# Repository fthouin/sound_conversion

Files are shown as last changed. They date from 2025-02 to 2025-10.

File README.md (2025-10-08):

# Sub Sound-Conversion
Convertissons 4 boites de transport en merisier baltique de lasers femtoseconde Lituanniens (Light Conversion) en subwoofers!

**Avant**



**Après**



## Objectifs
- Obtenir des basses plus profondes pour bien rendre la diversité de styles musicaux du collectif Cocktail Sonore
- Avoir des enceintes efficaces pour permettre l'utilisation de batteries
- Permettre le transport à vélo
- Donner une nouvelle vie à des matériaux usagés

## Matériaux
Les dimensions des boites sont contenues dans le fichier `boite_lightcon_C231999.FCStd` (voir le tableur `dim` à l'intérieur). Ce fichier peut être ouvert avec [FreeCAD](https://www.freecad.org/). Une photo des boites se trouve dans le fichier `boite.jpg`

## Moteur

La conception s'articule autour du [Eminence 12LFA](https://eminence.com/products/delta_12lfa) dont la feuille de spécification se trouve dans `\Datasheets`.

## Concept original

Nous basons notre conception sur le [POC7 de Brian Steele](https://www.diysubwoofers.org/projects/other/POC7/) modifié pour faciliter la construction avec les matériaux disponibles

## Modèles

Les modèles de conception et de fabrication sont contenus dans le fichier FreeCAD V1 `./Simulations/gfold.FCStd`. Les paramètres ajustables du modèle se trouvent dans le chiffrier `dims` du fichier. Les dimensions internes, le rapport entre la hauteure des premières et deuxièmes segments du chemin acoustique pliés et la hauteure totale de la boite ainsi que le décalage du driver par rapport au premier plis du tube peuvent être ajustés pour optimiser les performances acoustiques.

### Simulations
 Dans ce fichier, le dossier Simulations contient un objet `soundpath`. Celui-ci contient un dessin de la cavité acoustique et des quatres segments (`sound_path_X`) qui la compose. Leur longueur est automatiquement calculée et transcrite dans le chiffrier `hornresp`. Ce classeur contient aussi l'aire des sections de ces segments, elles-aussi automatiquement calculées.

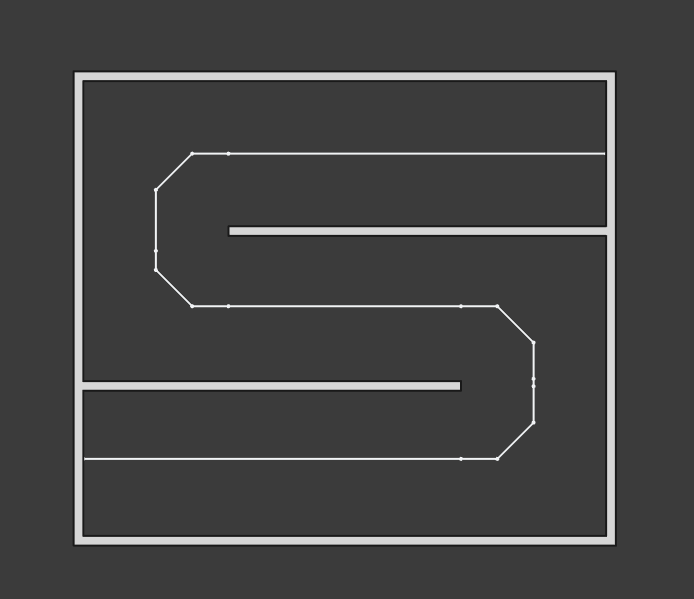
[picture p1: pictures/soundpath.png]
soundpath


Ces paramètres géométriques sont importés dans [HornResp](http://www.hornresp.net/) ainsi que les paramètres Thiele-Small du moteur. Le fichier contenant les dernières simulations est dans `Simulations\hornresp_sound_conversion.txt`

### Fabrication

Un modèle de la fabrication fidèle aux simulations est aussi automatiquement généré avec les paramètres entrées dans le chiffrier `dims`. Les dimensions qui en découlent se trouvent dans le chiffrier `bdim`. Les morceaux individuels se trouvent dans le dossier `Models` et sont importés dans `Assembly` pour le modèle d'assemblage. L'assemblage utilisent le module d'assemblage natif de FreeCad V1.

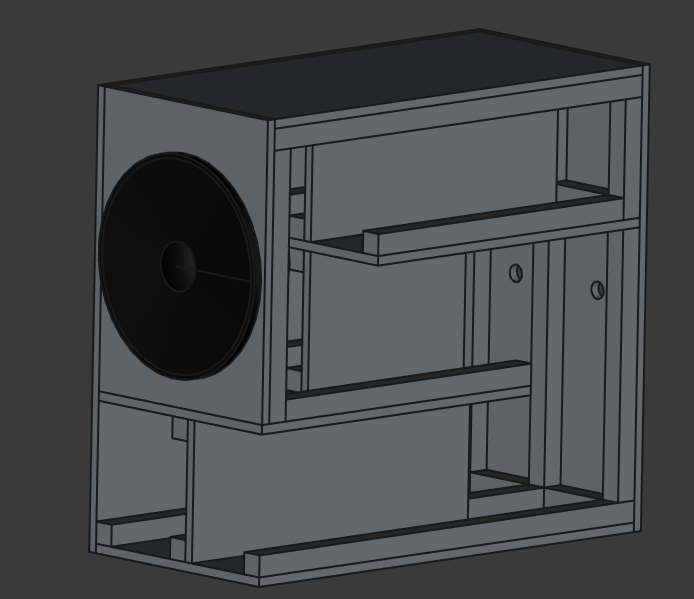
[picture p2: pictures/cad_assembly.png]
assembly


Des dessins techniques imprimables se trouvent dans le dossier `Drawings` du fichier. Ceux-ci sont automatiquement ajustés lorsque le modèle est changé. Ceux-ci décrivent les dimensions des matériaux originaux, les plans de coupe ainsi que les plans d'assemblage.

## Performance

### Simulations

Les performances attendues après avoir optimisé le concept sont présentées ci-dessous. Les paramètres de la simulation utilisé sont d'abord présentés. Ceux-ci considère le volume occupé par les supports et poutres dans les sections du chemin acoustique en soustrayant leur aire à l'aire calculée dans le chiffrier `hornresp` du fichier CAD. L'amplitude du signal est choisie pour garder l'excursion du moteur sous sa limite linéaire (Xmax=4.8mm) 

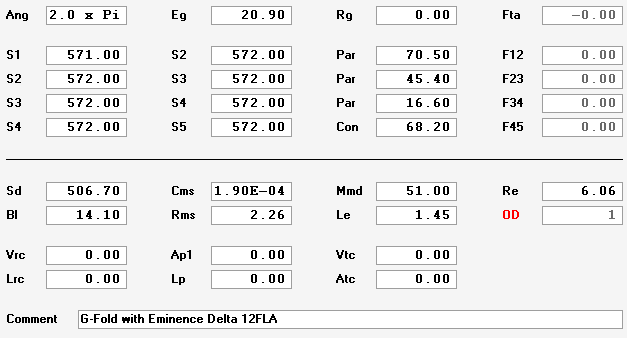
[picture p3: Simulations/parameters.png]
parameters


Le système simulé est schématisé ici:

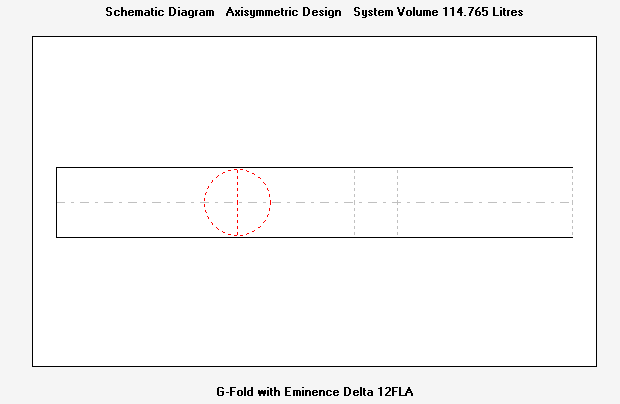
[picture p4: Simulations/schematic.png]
schematic


L'impédance acoustique et électrique vue du driver:

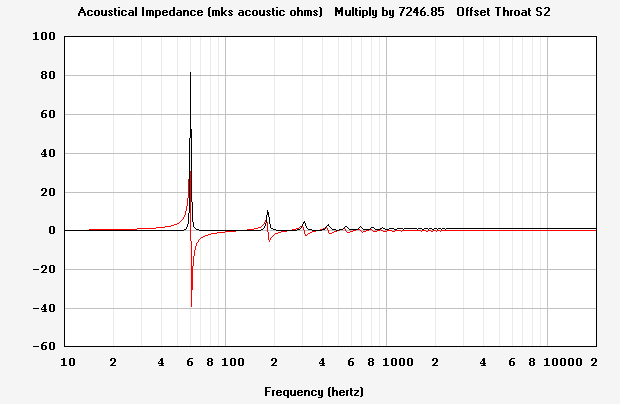
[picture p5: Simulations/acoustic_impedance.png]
acoustic_impedance

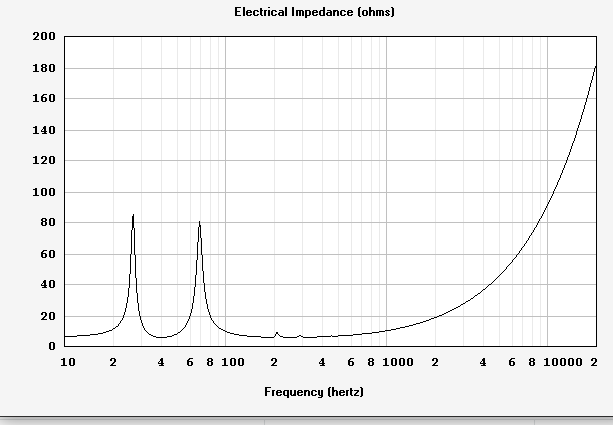
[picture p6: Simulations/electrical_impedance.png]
electrical_impedance


Afin de protéger le moteur de sur-excursions et de l'intégrer dans un système de son complets, un filter électronique en amont du subwoofer doit être conçu et utilisé. Nous avons posé la limite d'excursion maximale à celle du seuil de non-linéarité du manufacturier (Xmax=4.8mm).

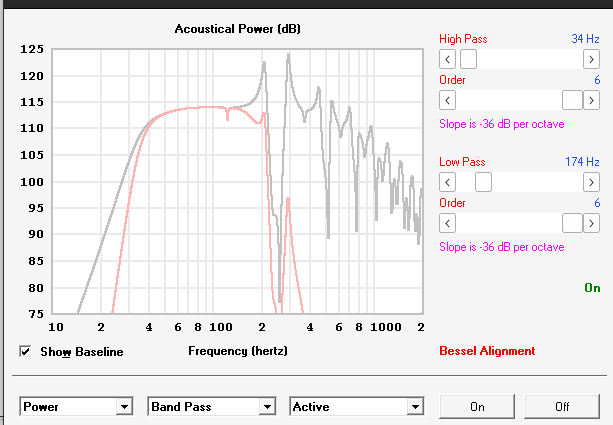
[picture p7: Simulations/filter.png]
filter


Le spectre d'excursion sans et avec filtre électronique en amont:

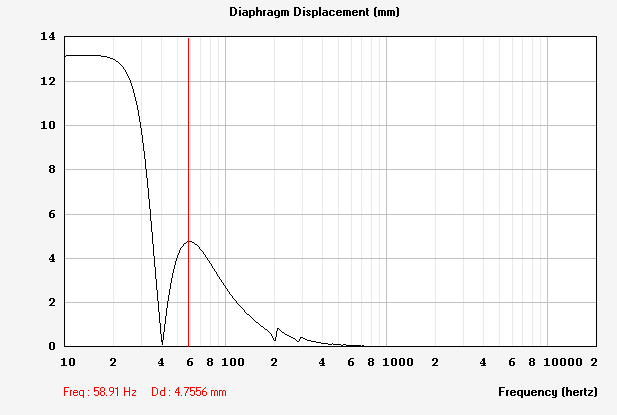
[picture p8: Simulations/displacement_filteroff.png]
displacement_filteroff

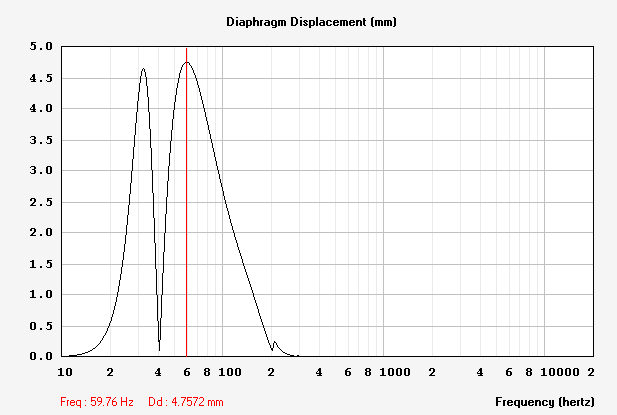
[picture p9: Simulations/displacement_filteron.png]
displacement_filteron


Le spectre de puissance acoustique combiné du driver et de la flute de résonnance sans et avec filtre électronique en amont:

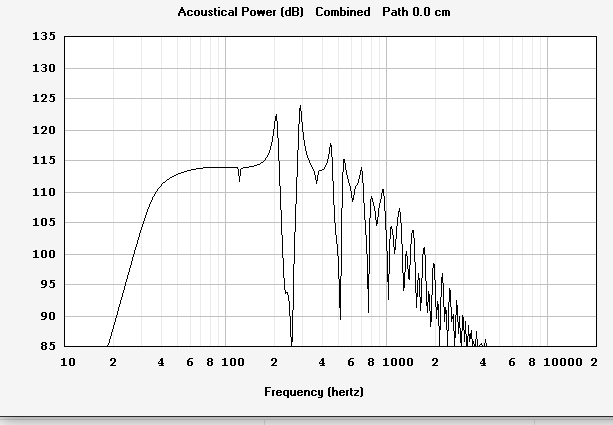
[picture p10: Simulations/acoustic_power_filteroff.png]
acoustic_power_filteroff

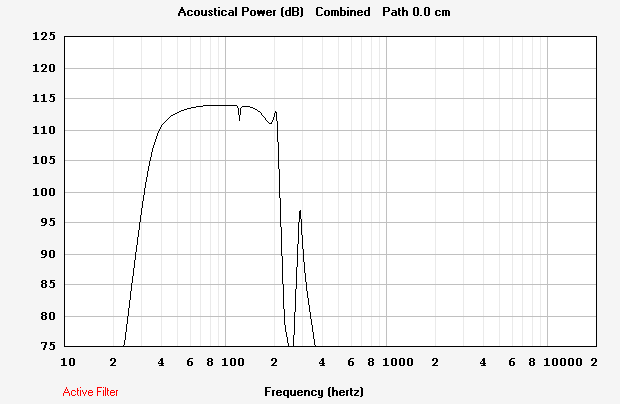
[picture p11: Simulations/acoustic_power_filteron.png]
acoustic_power_filteron


Le spectre de phase combiné du driver et de la flute de résonnance sans et avec filtre électronique en amont:

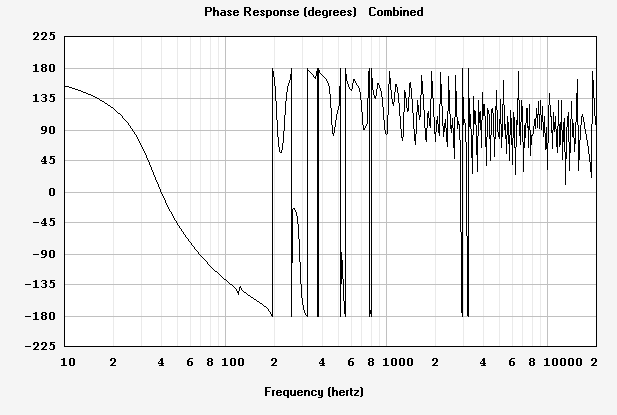
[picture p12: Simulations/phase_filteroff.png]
acoustic_phase_filteroff

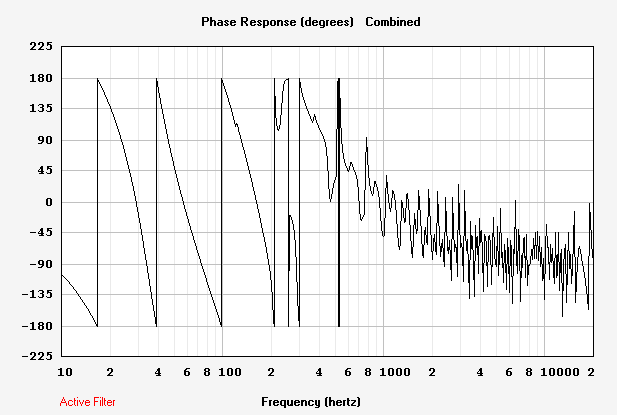
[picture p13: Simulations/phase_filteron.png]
acoustic_phase_filteron


Le délai de vitesse de groupe sans et avec filtre électronique en amont:

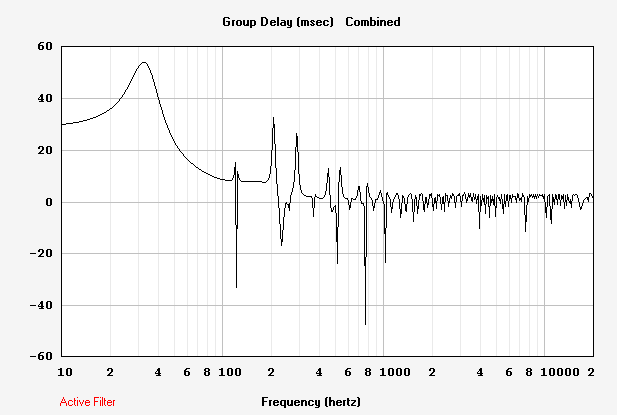
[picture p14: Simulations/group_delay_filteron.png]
group_delay_filteron

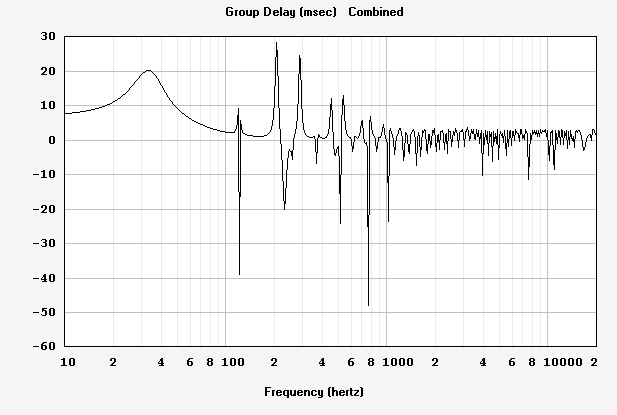
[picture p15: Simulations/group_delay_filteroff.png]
group_delay_filteroff


[soundpath]: pictures/soundpath.png "Sound path calculated in the CAD model"
[assembly]: pictures/cad_assembly.png "Assembly model"
[parameters]: Simulations/parameters.png "Parameters of HornResp simulation"
[schematic]: Simulations/schematic.png "Schematic of HornResp simulation"
[acoustic_impedance]: Simulations/acoustic_impedance.png "Simulated acoustic impedance of HornResp simulation"
[electrical_impedance]: Simulations/electrical_impedance.png "Simulated electrical impedance of HornResp simulation"
[filter]: Simulations/filter.png "Electronic filter characteristics"
[acoustic_power_filteron]: Simulations/acoustic_power_filteron.png "Simulated acoustic power with filter"
[acoustic_power_filteroff]: Simulations/acoustic_power_filteroff.png "Simulated acoustic power without filter"
[displacement_filteroff]: Simulations/displacement_filteroff.png "Simulated acoustic power without filter"
[displacement_filteron]: Simulations/displacement_filteron.png "Simulated acoustic power with filter"
[acoustic_phase_filteron]: Simulations/phase_filteron.png "Simulated acoustic phase with filter"
[acoustic_phase_filteroff]: Simulations/phase_filteroff.png "Simulated acoustic phase without filter"
[group_delay_filteron]: Simulations/group_delay_filteron.png "Simulated acoustic group delay with filter"
[group_delay_filteroff]: Simulations/group_delay_filteroff.png "Simulated acoustic group delay without filter"

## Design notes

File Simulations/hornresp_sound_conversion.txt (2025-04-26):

ID = 55.30

Comment = G-Fold with Eminence Delta 12FLA

|RADIATION, SOURCE AND MOUTH PARAMETER VALUES:

Ang = 2.0 x Pi
Eg = 20.90
Rg = 0.00
Fta = -0.00

|HORN PARAMETER VALUES:

S1 = 571.00
S2 = 572.00
Par = 70.50
F12 = 0.00
S2 = 572.00
S3 = 572.00
Par = 45.40
F23 = 0.00
S3 = 572.00
S4 = 572.00
Par = 16.60
F34 = 0.00
S4 = 572.00
S5 = 572.00
Con = 68.20
F45 = 0.00

|TRADITIONAL DRIVER PARAMETER VALUES:

Sd = 506.70
Bl = 14.10
Cms = 1.90E-04
Rms = 2.26
Mmd = 51.00
Le = 1.45
Re = 6.06
OD = 1

|ADVANCED DRIVER PARAMETER VALUES FOR SEMI-INDUCTANCE MODEL:

Re' = 0.00
Leb = 0.00
Le = 0.00
Ke = 0.00
Rss = 0.00

|ADVANCED DRIVER PARAMETER VALUES FOR FREQUENCY-DEPENDENT DAMPING MODEL:

Rms = 0.00
Ams = 0.00

|PASSIVE RADIATOR PARAMETER VALUE:

Added Mass = 0.00

|CHAMBER PARAMETER VALUES:

Vrc = 0.00
Lrc = 0.00
Ap1 = 0.00
Lp = 0.00
Vtc = 0.00
Atc = 0.00

Acoustic Path Length = 0.0

|MAXIMUM SPL PARAMETER VALUES:

Pamp = 100
Vamp = 25
Iamp = 4
Pmax = 450
Xmax = 5.0

Maximum SPL Setting = 3

|ABSORBENT FILLING MATERIAL PARAMETER VALUES:

Fr1 = 0.00
Fr2 = 0.00
Fr3 = 0.00
Fr4 = 0.00

Tal1 = 100
Tal2 = 100
Tal3 = 100
Tal4 = 100

|ACTIVE BAND PASS FILTER PARAMETER VALUES:

High Pass Frequency = 34
High Pass Slope = 1
Low Pass Frequency = 174
Low Pass Slope = 1

Butterworth High Pass Order = 6
Butterworth Low Pass Order = 6
Linkwitz-Riley High Pass Order = 6
Linkwitz-Riley Low Pass Order = 6
Bessel High Pass Order = 6
Bessel Low Pass Order = 6

2nd Order High Pass Q = 0.5
2nd Order Low Pass Q = 0.5
4th Order High Pass Q = 0.5
4th Order Low Pass Q = 0.5

Active Filter Alignment = 3
Active Filter On / Off Switch = 3

|PASSIVE FILTER PARAMETER VALUES:

Series / Parallel 1 = S
Series / Parallel 2 = S
Series / Parallel 3 = S
Series / Parallel 4 = S

|EQUALISER FILTER PARAMETER VALUES:

Band 1 Frequency = 0
Band 1 Q Factor = 0.01
Band 1 Gain = 0.0
Band 1 Type = -1
Band 2 Frequency = 0
Band 2 Q Factor = 0.01
Band 2 Gain = 0.0
Band 2 Type = -1
Band 3 Frequency = 0
Band 3 Q Factor = 0.01
Band 3 Gain = 0.0
Band 3 Type = -1
Band 4 Frequency = 0
Band 4 Q Factor = 0.01
Band 4 Gain = 0.0
Band 4 Type = -1
Band 5 Frequency = 0
Band 5 Q Factor = 0.01
Band 5 Gain = 0.0
Band 5 Type = -1
Band 6 Frequency = 0
Band 6 Q Factor = 0.01
Band 6 Gain = 0.0
Band 6 Type = -1

|STATUS FLAGS:

Auto Path Flag = 0
Lossy Inductance Model Flag = 0
Semi-Inductance Model Flag = 0
Damping Model Flag = 0
Closed Mouth Flag = 0
Continuous Flag = 1

|OTHER SETTINGS:

Filter Type Index = 0
Filter Input Index = 0
Filter Output Index = 0

Filter Type = 2

MEH Configuration = 0
ME Amplifier Polarity Value = 1

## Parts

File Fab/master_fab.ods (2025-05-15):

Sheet: Sheet1
Pièce | Matériel de base | Outils requis | Numéro de dessin | Pages | Qté requise | Qté construite
Panneau latéral | Planche B | Banc de scie | 1 | 1 | 2
Panneau dessus/dessous | Planche A | Banc de scie | 2 | 1 | 2

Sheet: Inventaire
Description | Provenance | W | H | T | # dispo | Utilisé pour | Coupe | Utilisé | Nombre utilisé | Restant | L1 (mm) | L2 (mm) | L1 (in) | L2( in)
Bar arrière longue | Assemblage C | 635 | 30 | 30 | 4 |  |  |  | 4 | 0
 |  |  |  |  |  | (brace_bar_back_panel_a,brace_bar_back_panel_f), (brace_bar_back_panel_b,brace_bar_back_panel_c) | W | 536.03 | 2 | 98.97 | 372 | 164 | 14.63 | 6.47
 |  |  |  |  |  | (brace_bar_back_panel_d,e) | W | 506.03 | 1 | 128.97 | 372 | 134 | 14.63 | 5.29
 |  |  |  |  |  | middle_brace_bar_fin_2 | W | 505.67 | 1 | 129.33 | 506 |  | 19.91
Bar longue côtés | Assemblage B | 1115 | 30 | 30 | 7 |  |  |  | 6 | 1
 |  |  |  |  |  | (side_panel_1_a,middle_brace_bar_fin_1and2_fin2) | W | 959.34 | 1 | 155.66 | 674 | 285 | 26.54 | 11.23
 |  |  |  |  |  | (side_panel_1_b,middle_brace_bar_fin_1and2_fin1) | W | 959.34 | 1 | 155.66 | 674 | 285 | 26.54 | 11.23
 |  |  |  |  |  | (side_panel_2_a, )(side_panel_2_b,) | W | 687 | 2 | 428 | 687 |  | 27.05
 |  |  |  |  |  | (middle_brace_bar_side_panel_2, brace_bar_fin_2_a) | W | 1106.86 | 1 | 8.13999999999987 | 450 | 657 | 17.71 | 25.87
 |  |  |  |  |  | (middle_brace_bar_side_panel_1, middle_brace_bar_fin_1) | W | 1063.67 | 1 | 51.3299999999999 | 614 | 450 | 24.17 | 17.70
Barres courte côtés | Assemblage B | 260 | 30 | 30 | 8 |  |  |  | 5 | 3
 |  |  |  |  |  | side_panel_2_c, side_panel_1_c,d | Tel quel | 260 | 3 | 0 | 260 |  | 10.24
 |  |  |  |  |  | cross_brace_fin_1,2 | tel quel | 260 | 2 | 0 | 260 |  | 10.24
barre longue coté endommagée | Assemblage B | 760 | 30 | 30 | 1 |  |  |  | 1 | 0
 |  |  |  |  |  | (middle_brace_bar_fin_1and_2_fin1,middle_brace_bar_fin_1and_2_fin2) | w | 570.68 | 1 | 189.32 | 285 | 285 | 11.23 | 11.23
barres longue avant | Assemblage C | 635 | 30 | 30 | 5 |  |  |  | 5 | 0
 |  |  |  |  |  | (front_panel_bar_a, driver_brace_bar_a) | w | 521.66 | 1 | 113.34 | 150 | 372 | 5.91 | 14.63
 |  |  |  |  |  | (front_panel_bar_b, driver_brace_bar_b) | w | 521.66 | 1 | 113.34 | 150 | 372 | 5.91 | 14.63
 |  |  |  |  |  | brace_bar_fin_1_a,b | w | 449.67 | 2 | 185.33 | 450 |  | 17.70
 |  |  |  |  |  | brace_bar_fin_2_b | W | 449.67 | 1 | 185.33 | 450 |  | 17.70

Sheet: Prép Assemblage
1 | Compléter l’assemblage avec des vis seulement pour vérifier la conformité de la structure
 | Utiliser le nombre de vis spécifiée à côté de la pièce
 | Répartir les vis uniformément sur la pièce
 | Mesurer ssssss

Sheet: Assemblage 1
 | Nom
1 | SASS1 | Fixer les pièces des assemblages de côté (1) | Dessin: Assemblage: Side Panel 1
 |  |  | # de pièce dans dessin | nom de la pièce
 |  |  | 1 | side_panel_1_bar_d
 |  |  | 2 | side_panel_1_bar_a
 |  |  | 3 | side_panel_1_bar_b
 |  |  | 4 | middle_brace_bar_side_panel_1
 |  |  | 5 | side_panel_1_bar_c
 |  |  | P3 | Panneau P3
2 | SASS2 | Fixer les pièces des assemblages de côté (2) | Dessin: Assemblage: Side Panel 2
 |  |  | # de pièce dans dessin | nom de la pièce
 |  |  | 1 | side_panel_2_bar_a
 |  |  | 2 | middle_brace_bar_side_panel_2
 |  |  | 3 | side_panel_2_bar_b
 |  |  | 4 | side_panel_1_bar_c
 |  |  | P4 | Panneau P4
3 | FASS | Fixer les pièces de l'assemblage de face | Dessin: Assemblage: Front Panel
 |  |  | # de pièce dans dessin | nom de la pièce
 |  |  | 2 | front_panel_bar_a
 |  |  | 3 | front_panel_bar_b
 |  |  | 4 | cross_brace_fin_2
 |  |  | P5 | Panneau P5
4 | BSASS | Assemblages de côtés et derrière (1) | Dessin: Back Side Assembly
 |  |  | # de pièce dans dessin | nom de la pièce
 |  |  | 1 | brace_bar_back_panel_f
 |  |  | 2 | brace_bar_back_panel_a
 |  |  | 3 | cross_brace_fin_1
 |  |  | P6 | Panneau P6
 |  |  | P8 | Panneau P8
5 | BSFASS | Ajout FASS | Dessin: Front add assembly
 |  |  | # de pièce dans dessin | nom de la pièce
 |  |  | 1 | driver_brace_bar_a
 |  |  | 2 | driver_brace_bar_b
6 | ASSMB1 | Ajout P1 | Dessin: Bottom add assembly
 |  |  | # de pièce dans dessin | nom de la pièce
 |  |  | P1 | Panneau P1
7 | ASSMB2 | Ajout fond de caisse | Dessin: Bottom Fin Support
 |  |  | # de pièce dans dessin | nom de la pièce
 |  |  | P7 | Panneau P7
 |  |  | 2 | brace_bar_fin_2_b
 |  |  | 3 | brace_bar_fin_1_a
8 | ASSMB3 | Ajout poutres centrales | Dessin: Middle Brace
 |  |  | # de pièce dans dessin | nom de la pièce
 |  |  | 1 | brace_bar_back_panel_e
 |  |  | 2 | middle_brace_bar_fin_1
 |  |  | 3 | middle_brace_bar_fin_1and_2_fin1
 |  |  | 4 | brace_bar_back_panel_d
 |  |  | 5 | middle_brace_bar_fin_1and_2_fin2
 |  |  | 6 | middle_brace_bar_fin_2
9 | ASSMB4 | Ajout panneaux de support verticaux | Dessin: Middle fin support
 |  |  | # de pièce dans dessin | nom de la pièce
 |  |  | P10 | Panneau P10
 |  |  | P11 | Panneau P11
 |  |  | P9 | Panneau P9
10 | ASSMB5 | Ajout poutres du dessus | Dessin: Top Brace
 |  |  | # de pièce dans dessin | nom de la pièce
 |  |  | 1 | brace_bar_back_panel_c
 |  |  | 2 | brace_bar_fin_1_b
 |  |  | 3 | brace_bar_fin_2_a
10 | ASSMB | Fermeture | Dessin: close it up!
 |  |  | # de pièce dans dessin | nom de la pièce
 |  |  | P2 | Panneau P2

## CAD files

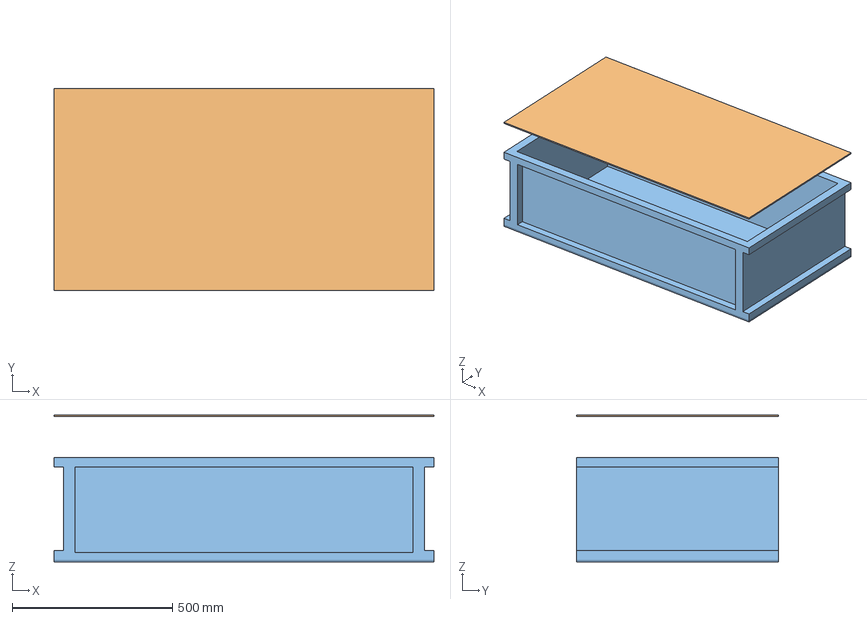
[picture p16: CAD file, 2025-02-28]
Boxes/boite_lightcon_C231999.FCStd
1186.0 x 632.0 x 458.0 mm
TopPanel
Slice

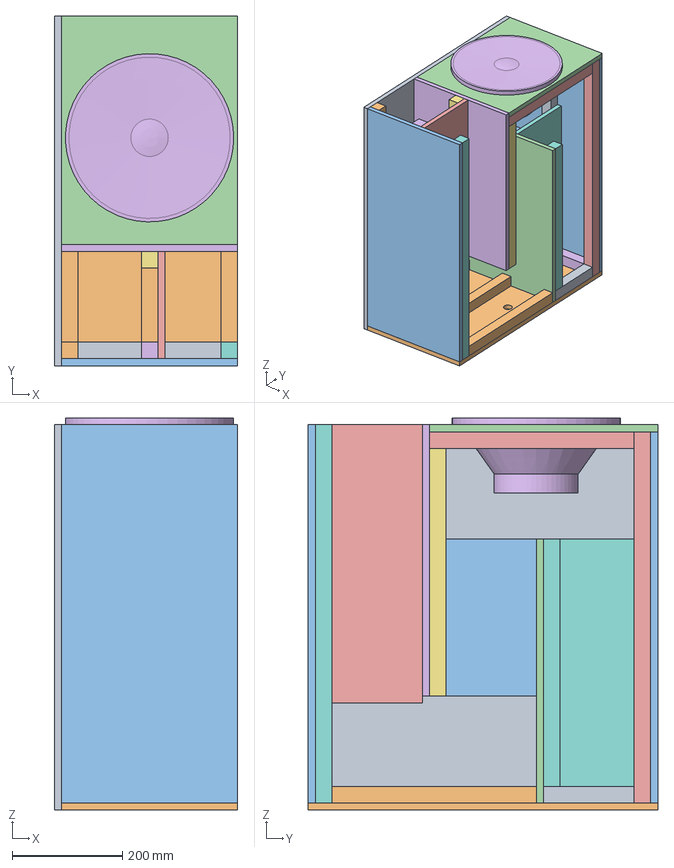
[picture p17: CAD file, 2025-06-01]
Simulations/gfold.FCStd
333.0 x 635.0 x 712.2 mm
bottom_panel
back_panel
side_panel_001
side_panel_001_bar_001
side_panel_001_bar_002
side_panel_001_bar_003
side_panel_001_bar_004 x 3
side_panel_002_bar_001
side_panel_002_bar_004
side_panel_002_bar_002
side_panel_002
front_panel
fp_bar_1 x 2
12lfa_driver
brace bar fin 2 x 2
brace bar fin 1 x 2
brace_bar_back_panel_1 x 2
brace_bar_back_panel_2 x 3
middle brace bar fin 1 model
driver_brace_bar x 2
fin 2 support
middle_brace_bar_side_panel_003
middle_brace_bar_fin_2_model
fin 1 support
middle_brace_bar_side_panel_1_model
middle_brace_bar_fin_1and_2 x 2
fin_support_1and2
fin_1_model
middle_brace_bar_back_panel_2_model
fin_2_model

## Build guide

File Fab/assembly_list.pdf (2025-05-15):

Assemblage 1

| A | B | C | D | E
1 | | Nom
2 | 1 | SASS1 | Fixer les pièces des assemblages de côté (1) | Dessin: Assemblage: Side Panel 1
3 | | | | # de pièce dans dessin | nom de la pièce
4 | | | | 1 | side_panel_1_bar_d
5 | | | | 2 | side_panel_1_bar_a
6 | | | | 3 | side_panel_1_bar_b
7 | | | | 4 | middle_brace_bar_side_panel_1
8 | | | | 5 | side_panel_1_bar_c
9 | | | | P3 | Panneau P3
10 | 2 | SASS2 | Fixer les pièces des assemblages de côté (2) | Dessin: Assemblage: Side Panel 2
11 | | | | # de pièce dans dessin | nom de la pièce
12 | | | | 1 | side_panel_2_bar_a
13 | | | | 2 | middle_brace_bar_side_panel_2
14 | | | | 3 | side_panel_2_bar_b
15 | | | | 4 | side_panel_1_bar_c
16 | | | | P4 | Panneau P4
17 | 3 | FASS | Fixer les pièces de l'assemblage de face | Dessin: Assemblage: Front Panel
18 | | | | # de pièce dans dessin | nom de la pièce
19 | | | | 2 | front_panel_bar_a
20 | | | | 3 | front_panel_bar_b
21 | | | | 4 | cross_brace_fin_2
22 | | | | P5 | Panneau P5
23 | 4 | BSASS | Assemblages de côtés et derrière (1) | Dessin: Back Side Assembly
24 | | | | # de pièce dans dessin | nom de la pièce
25 | | | | 1 | brace_bar_back_panel_f
26 | | | | 2 | brace_bar_back_panel_a
27 | | | | 3 | cross_brace_fin_1
28 | | | | P6 | Panneau P6
29 | | | | P8 | Panneau P8
30 | 5 | BSFASS | Ajout FASS | Dessin: Front add assembly
31 | | | | # de pièce dans dessin | nom de la pièce
32 | | | | 1 | driver_brace_bar_a
33 | | | | 2 | driver_brace_bar_b
34 | 6 | ASSMB1 | Ajout P1 | Dessin: Bottom add assembly
35 | | | | # de pièce dans dessin | nom de la pièce
36 | | | | P1 | Panneau P1
37 | 7 | ASSMB2 | Ajout fond de caisse | Dessin: Bottom Fin Support
38 | | | | # de pièce dans dessin | nom de la pièce
39 | | | | P7 | Panneau P7
40 | | | | 2 | brace_bar_fin_2_b
41 | | | | 3 | brace_bar_fin_1_a
42 | 8 | ASSMB3 | Ajout poutres centrales | Dessin: Middle Brace
43 | | | | # de pièce dans dessin | nom de la pièce
44 | | | | 1 | brace_bar_back_panel_e
45 | | | | 2 | middle_brace_bar_fin_1
46 | | | | 3 | middle_brace_bar_fin_1and_2_fin1
47 | | | | 4 | brace_bar_back_panel_d
48 | | | | 5 | middle_brace_bar_fin_1and_2_fin2
49 | | | | 6 | middle_brace_bar_fin_2
50 | 9 | ASSMB4 | Ajout panneaux de support verticaux | Dessin: Middle fin support
51 | | | | # de pièce dans dessin | nom de la pièce
52 | | | | P10 | Panneau P10
53 | | | | P11 | Panneau P11
54 | | | | P9 | Panneau P9
55 | 10 | ASSMB5 | Ajout poutres du dessus | Dessin: Top Brace
56 | | | | # de pièce dans dessin | nom de la pièce
57 | | | | 1 | brace_bar_back_panel_c
58 | | | | 2 | brace_bar_fin_1_b
59 | | | | 3 | brace_bar_fin_2_a
60 | 10 | ASSMB | Fermeture | Dessin: close it up!
61 | | | | # de pièce dans dessin | nom de la pièce
62 | | | | P2 | Panneau P2

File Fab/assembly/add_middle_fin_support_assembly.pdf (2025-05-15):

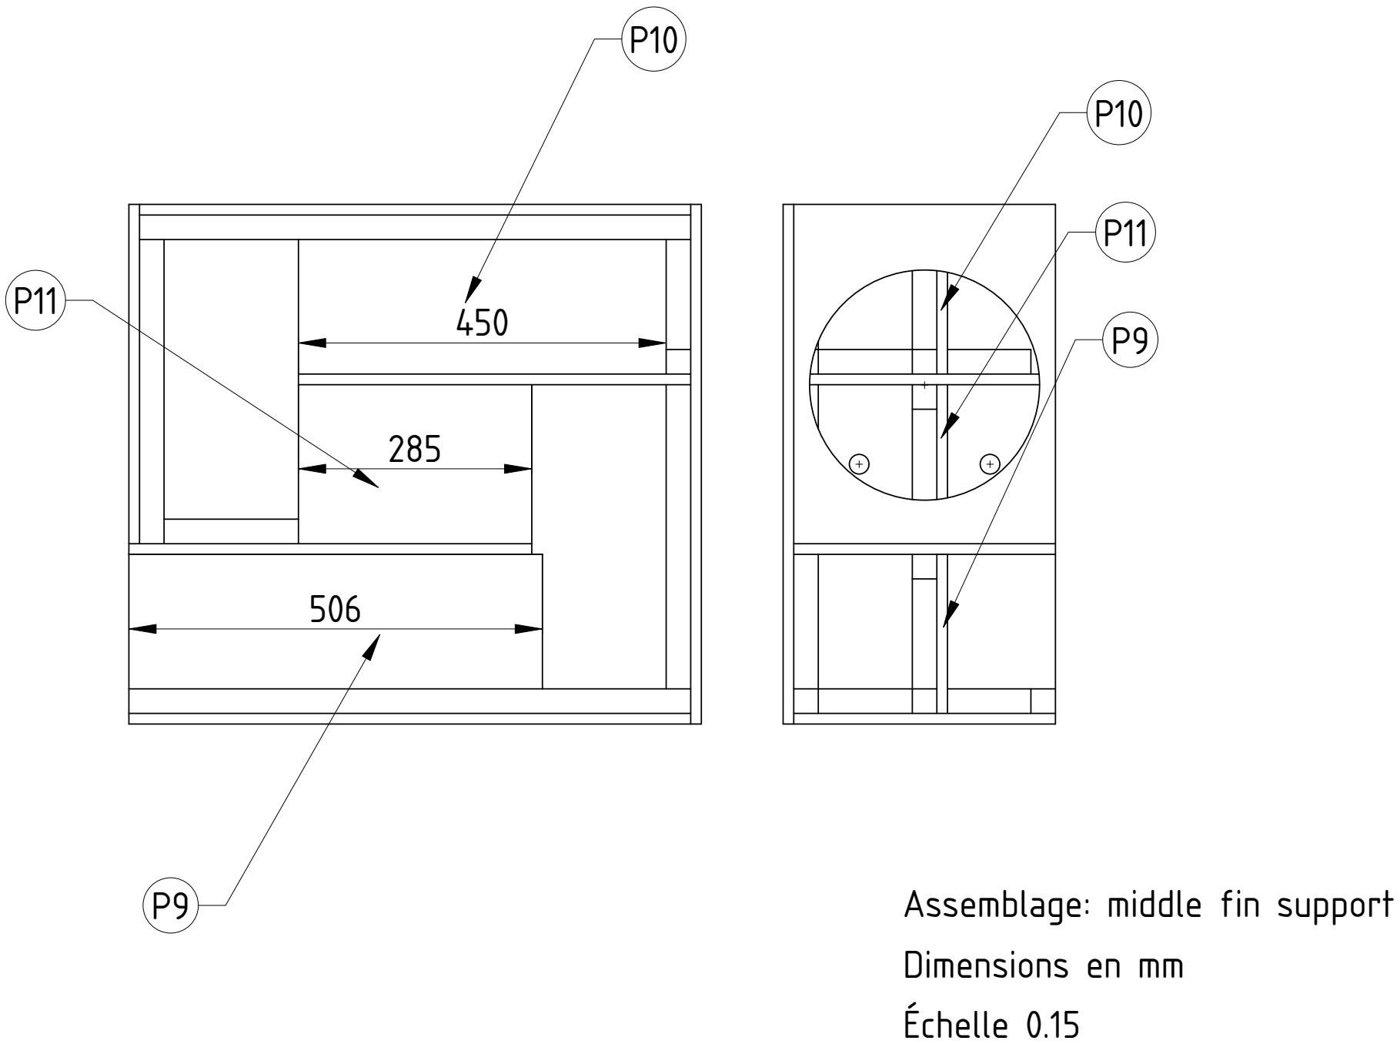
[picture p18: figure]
Assemblage: middle fin support; Dimensions en mm Échelle 0.15
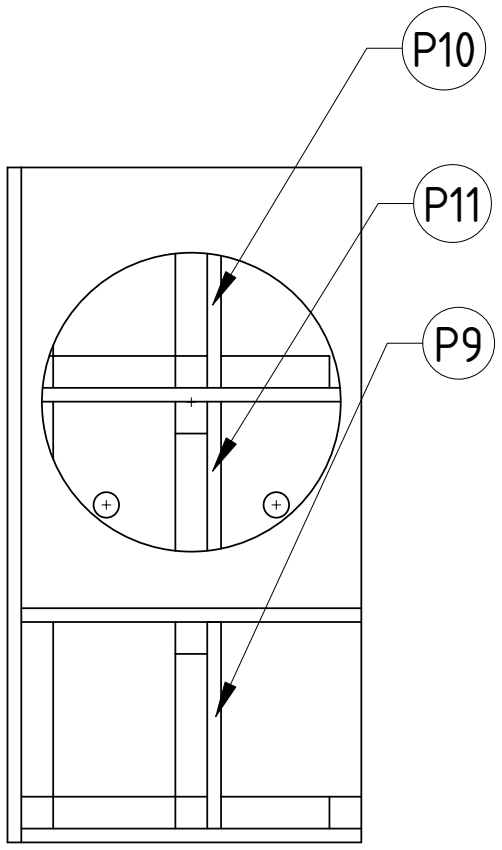
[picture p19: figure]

Répéter pour prime

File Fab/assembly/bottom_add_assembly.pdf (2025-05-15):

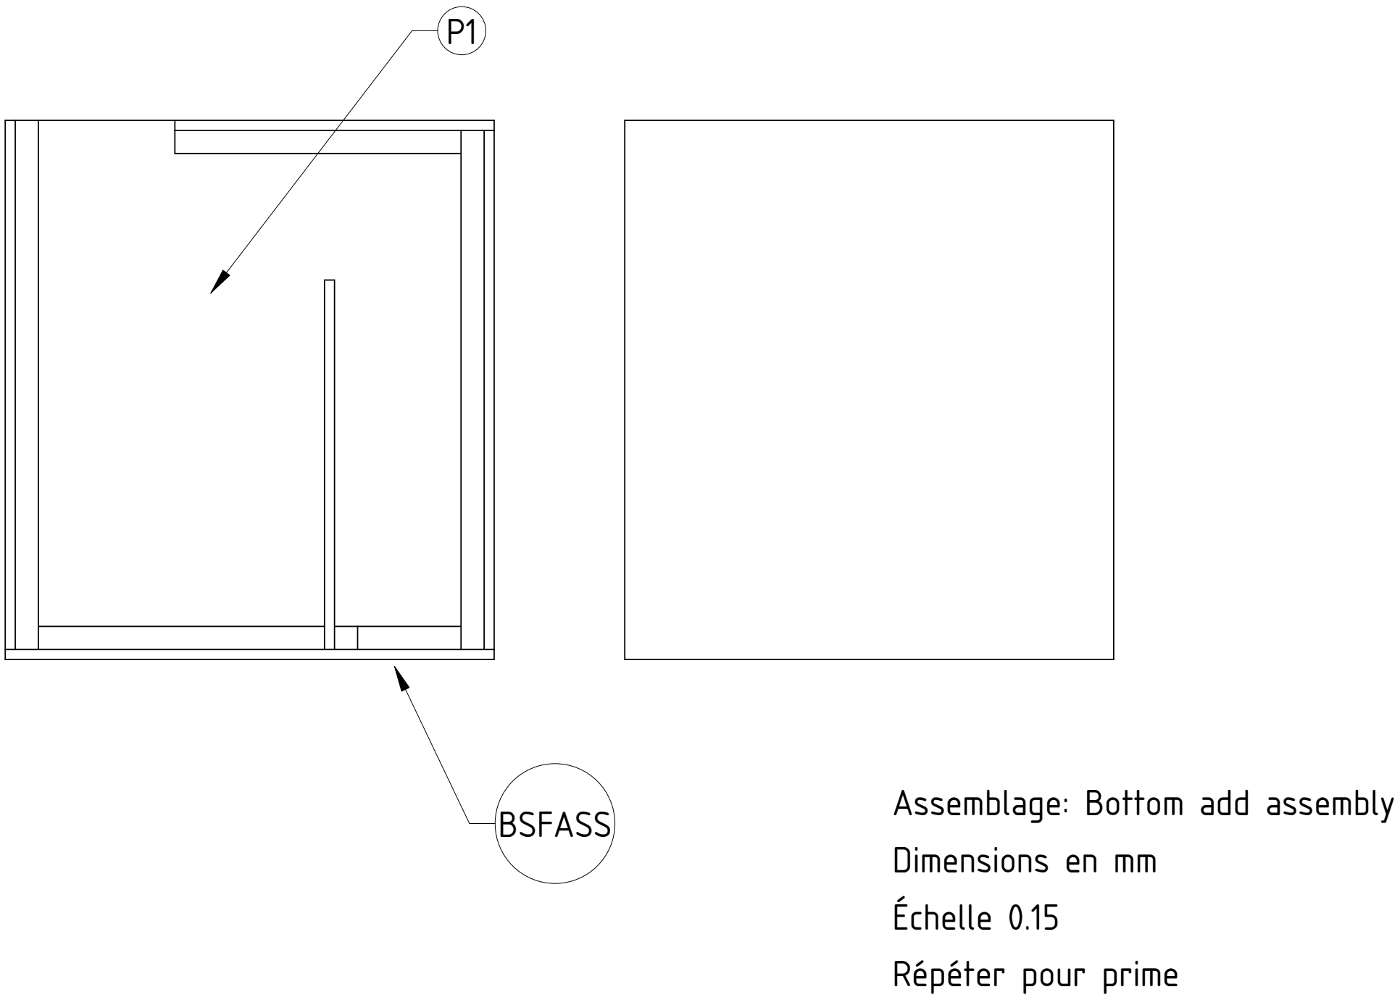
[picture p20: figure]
BSFASS; Assemblage: Bottom add assembly; Dimensions en mm Échelle 0.15 Répéter pour prime

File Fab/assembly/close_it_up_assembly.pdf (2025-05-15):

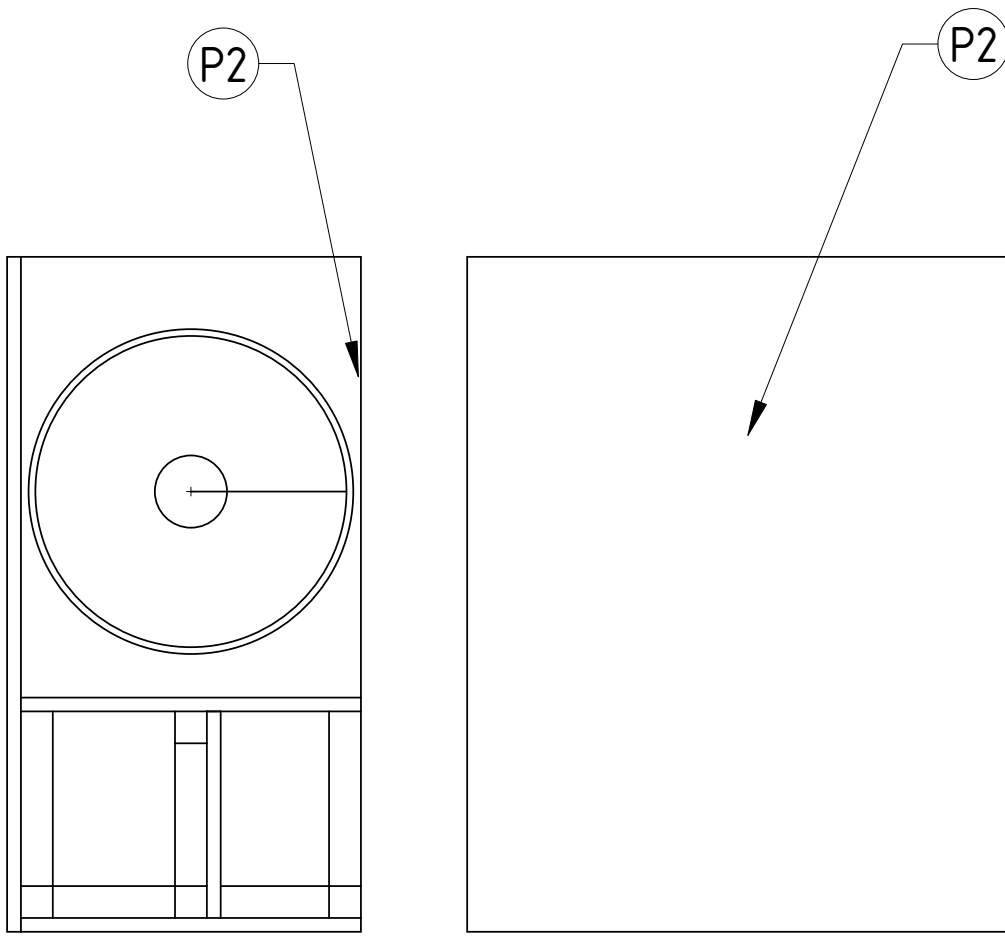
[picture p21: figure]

Assemblage: close it up!
Dimensions en mm
Échelle 0.15
Répéter pour prime

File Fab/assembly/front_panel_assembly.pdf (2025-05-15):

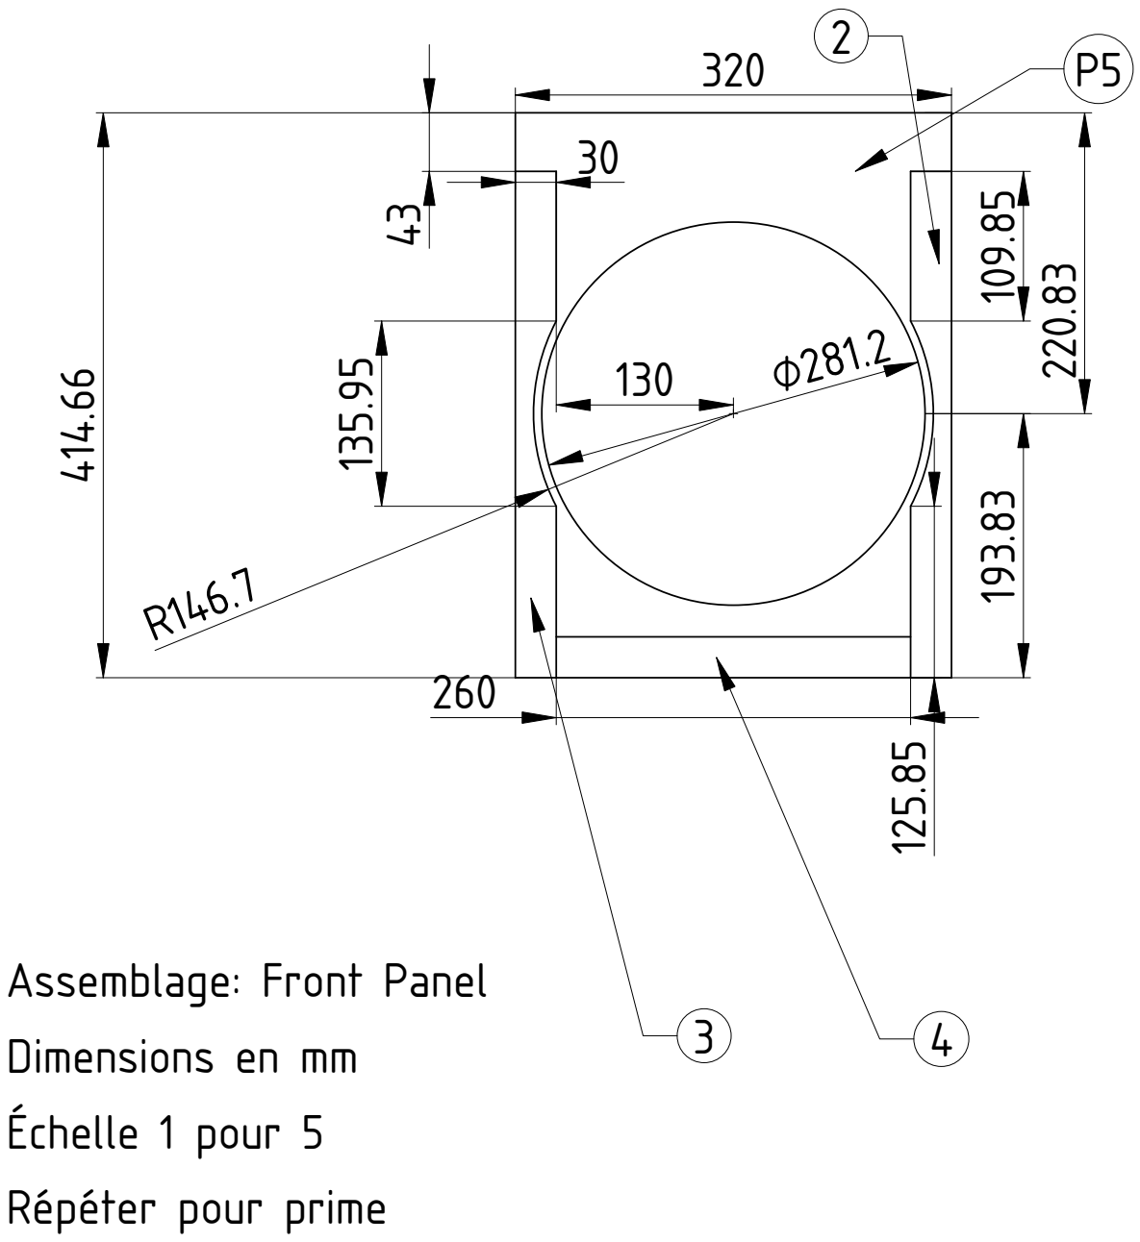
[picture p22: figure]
Assemblage: Front Panel Dimensions en mm Échelle 1 pour 5 Répéter pour prime
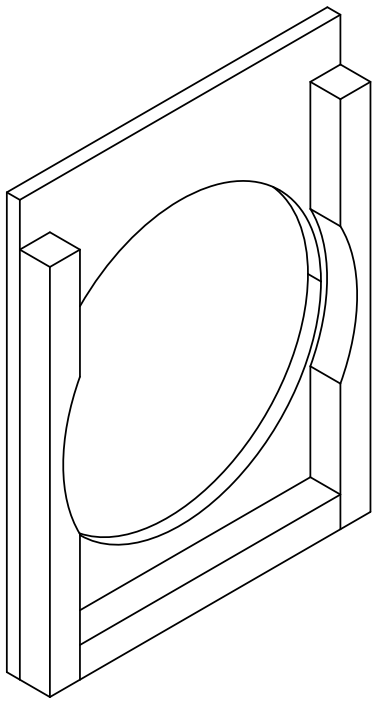
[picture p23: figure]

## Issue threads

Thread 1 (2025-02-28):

Électronique d'amplification et de cross-over

fthouin, 2025-02-28:
Faudrait qu'on y réfléchisse et qu'on détermine:
- Le système d'amplification désiré. Geoffroy avait un design d'amplificateur classe D homemade mais on pourrait aussi vouloir utiliser un appareil commercial.
- Alimentation: Il faudra aussi réfléchir à la stratégie d'alimentation. Des options possibles sont de recycler des sources d'alimentation (alimentation de vieux laptop, de vieil ordinateur), d'en acheter des neuves ou de les fabriquer nous même. Goeffroy a mentionné avoir un design de SMPS.
- Passif ou actif?: Est-ce qu'on veut que l'enceinte soit passive (seulement un connecteur vers le speaker) ou active (amplificateur et alimentation intégrée dans le boitier de l'enceinte?
- Crossover: Est-ce qu'on veut un crossover passif, actif analogue ou digital (DSP)? Veux-t-on qu'il soit intégré dans l'enceinte ou pas?

fthouin, 2025-03-09:
Je viens de tomber sur un repo pour un [DSP Open-Source](https://freedsp.github.io/)! On pourrait l'essayer!

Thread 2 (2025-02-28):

Transport

fthouin, 2025-02-28:
Ce système doit être transportable sans devoir nécessairement louer un camion ou une voiture. Il faudrait concevoir un système pour le transporter, que ce soit en s'assurant qu'il puisse être intégrer à une remorque de vélo ou en intégrant dans sa conception un système de mobilité.

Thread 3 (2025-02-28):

Conception acoustique

fthouin, 2025-02-28:
Simulation du commit ID `4663330`:

# Boxplan

Le boxplan a cette geule

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

avec ces dimensions. La seule coupe requise est la longueure de la boite.

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

# Simulations HornResp

je ne suis pas sur des paramètres Vrc, Lrc, Vtc et Atc. Est-ce que je me trompe?

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

Le placement du driver semble correct

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

et le spectre de puissance acoustique aussi.

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

et le délai de groupe

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

La réponse m'a l'air très bien jusqu'à 80Hz. On pourrait placer le crossover là.

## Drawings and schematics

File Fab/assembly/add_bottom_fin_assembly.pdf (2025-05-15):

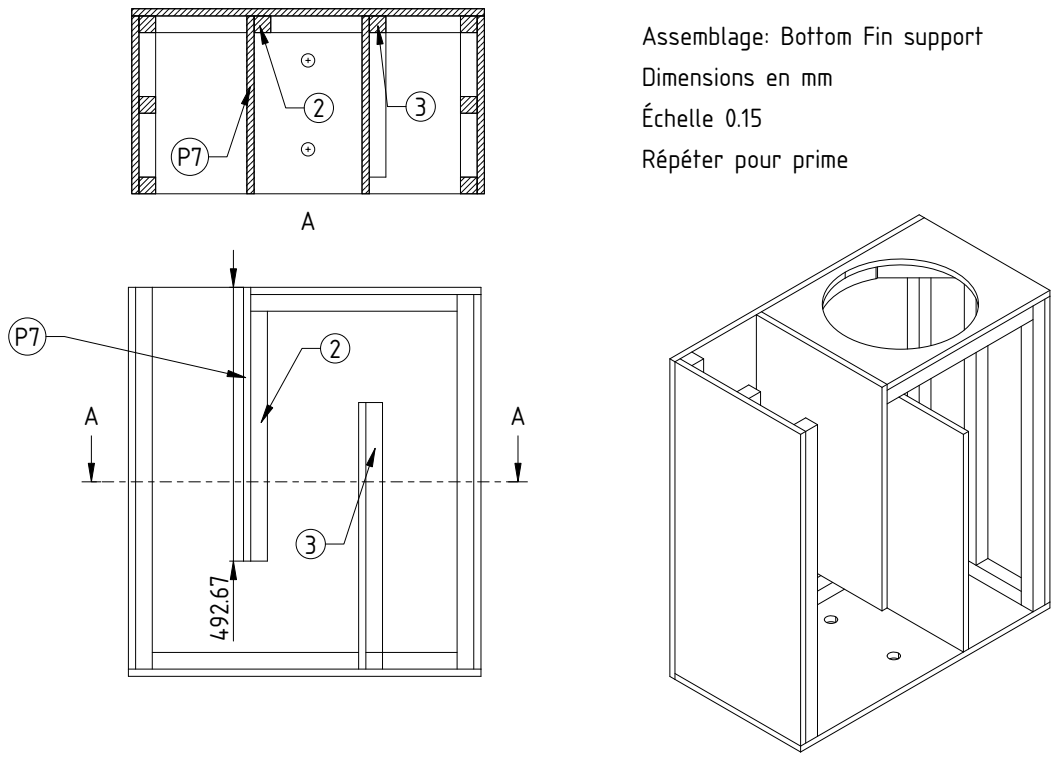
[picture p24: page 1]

Assemblage: Bottom Fin support
Dimensions en mm
Échelle 0.15
Répéter pour prime

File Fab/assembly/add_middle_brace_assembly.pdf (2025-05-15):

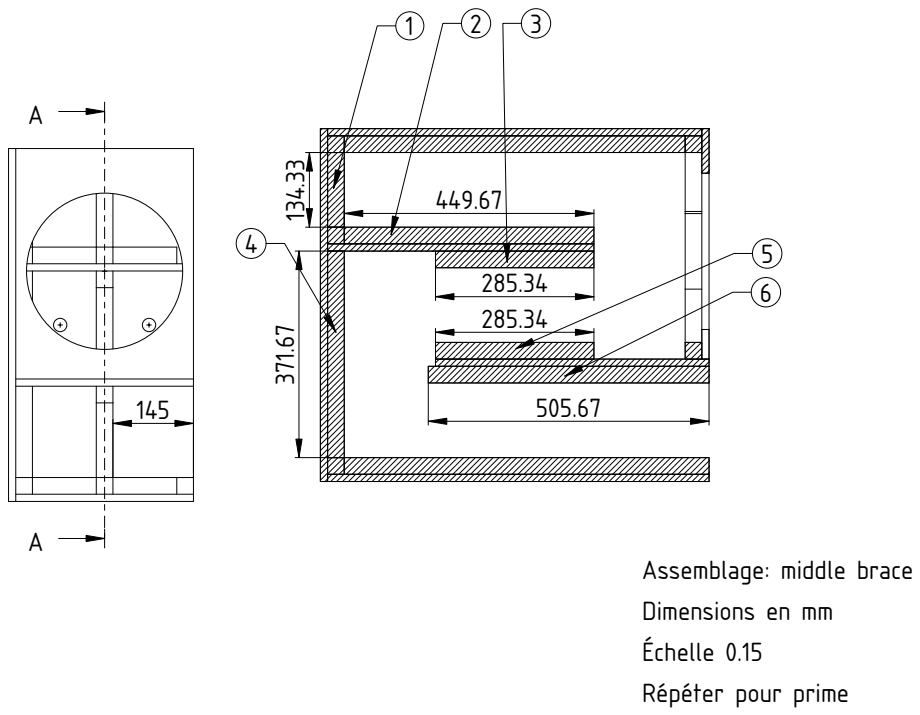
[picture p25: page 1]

Assemblage: middle brace
Dimensions en mm
Échelle 0.15
Répéter pour prime

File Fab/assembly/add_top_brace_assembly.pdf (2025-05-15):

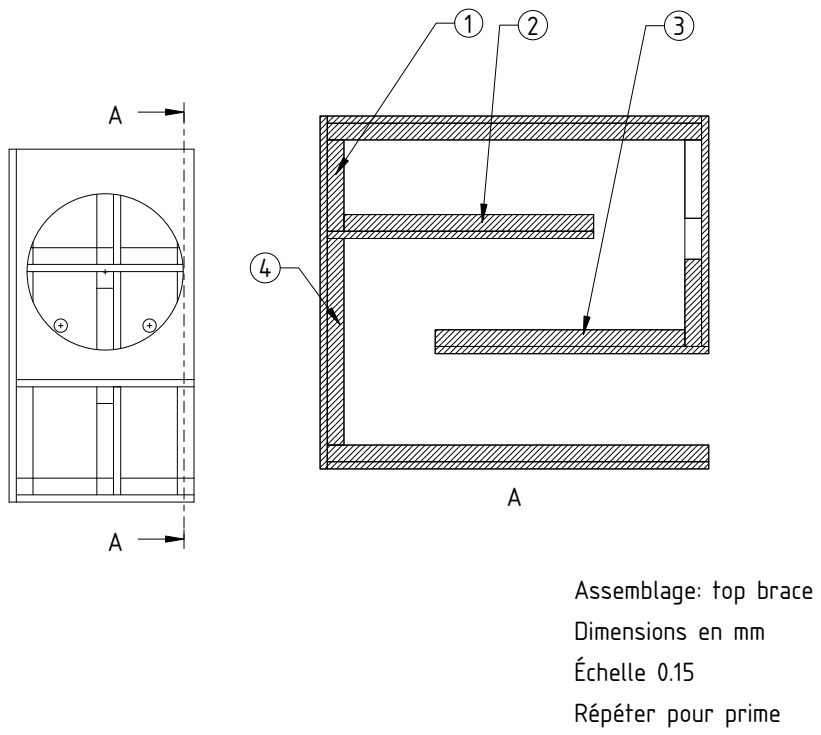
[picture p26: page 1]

Assemblage: top brace
Dimensions en mm
Échelle 0.15
Répéter pour prime

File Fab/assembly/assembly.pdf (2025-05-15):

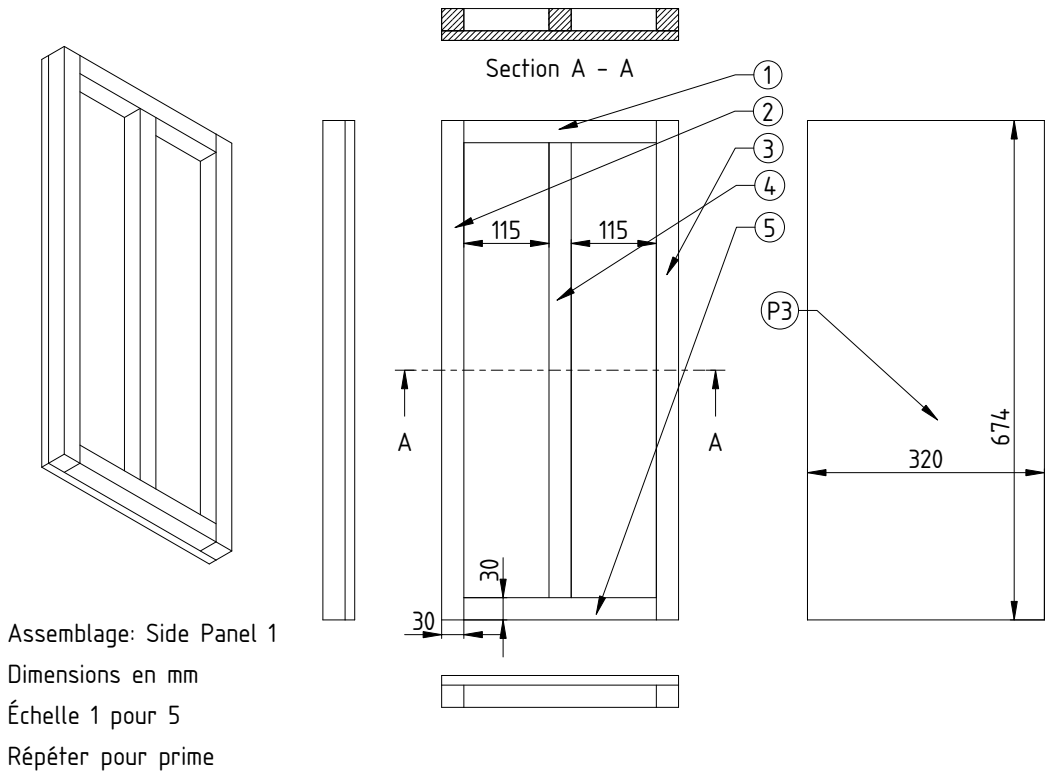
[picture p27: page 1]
Section A - A

Assemblage: Side Panel 1
Dimensions en mm
Échelle 1 pour 5
Répéter pour prime

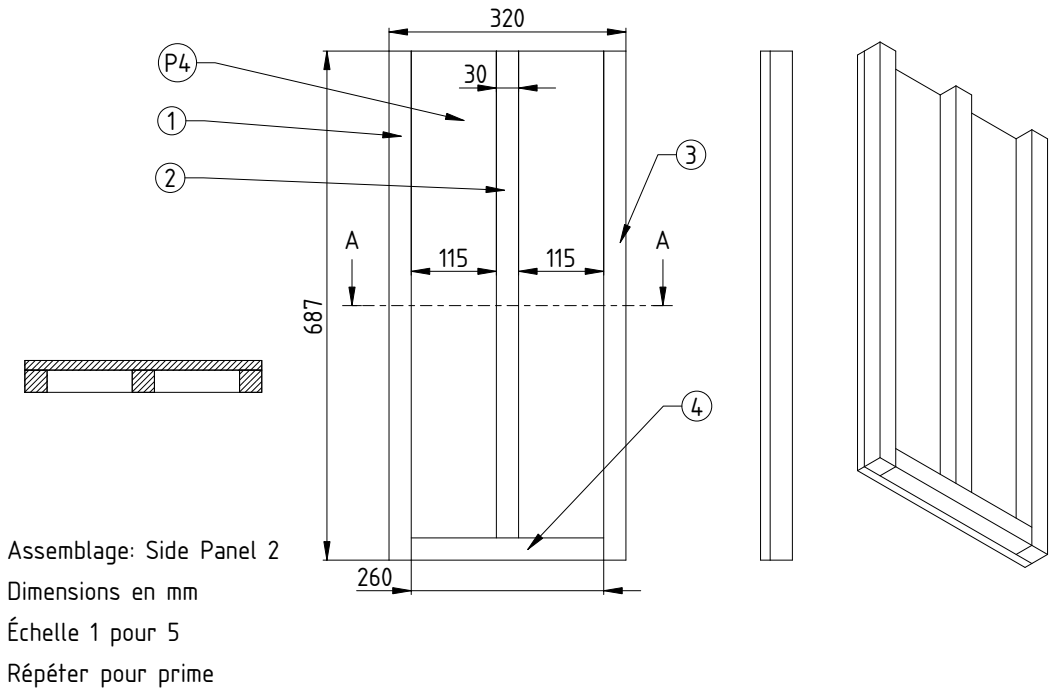
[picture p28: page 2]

Assemblage: Side Panel 2
Dimensions en mm
Échelle 1 pour 5

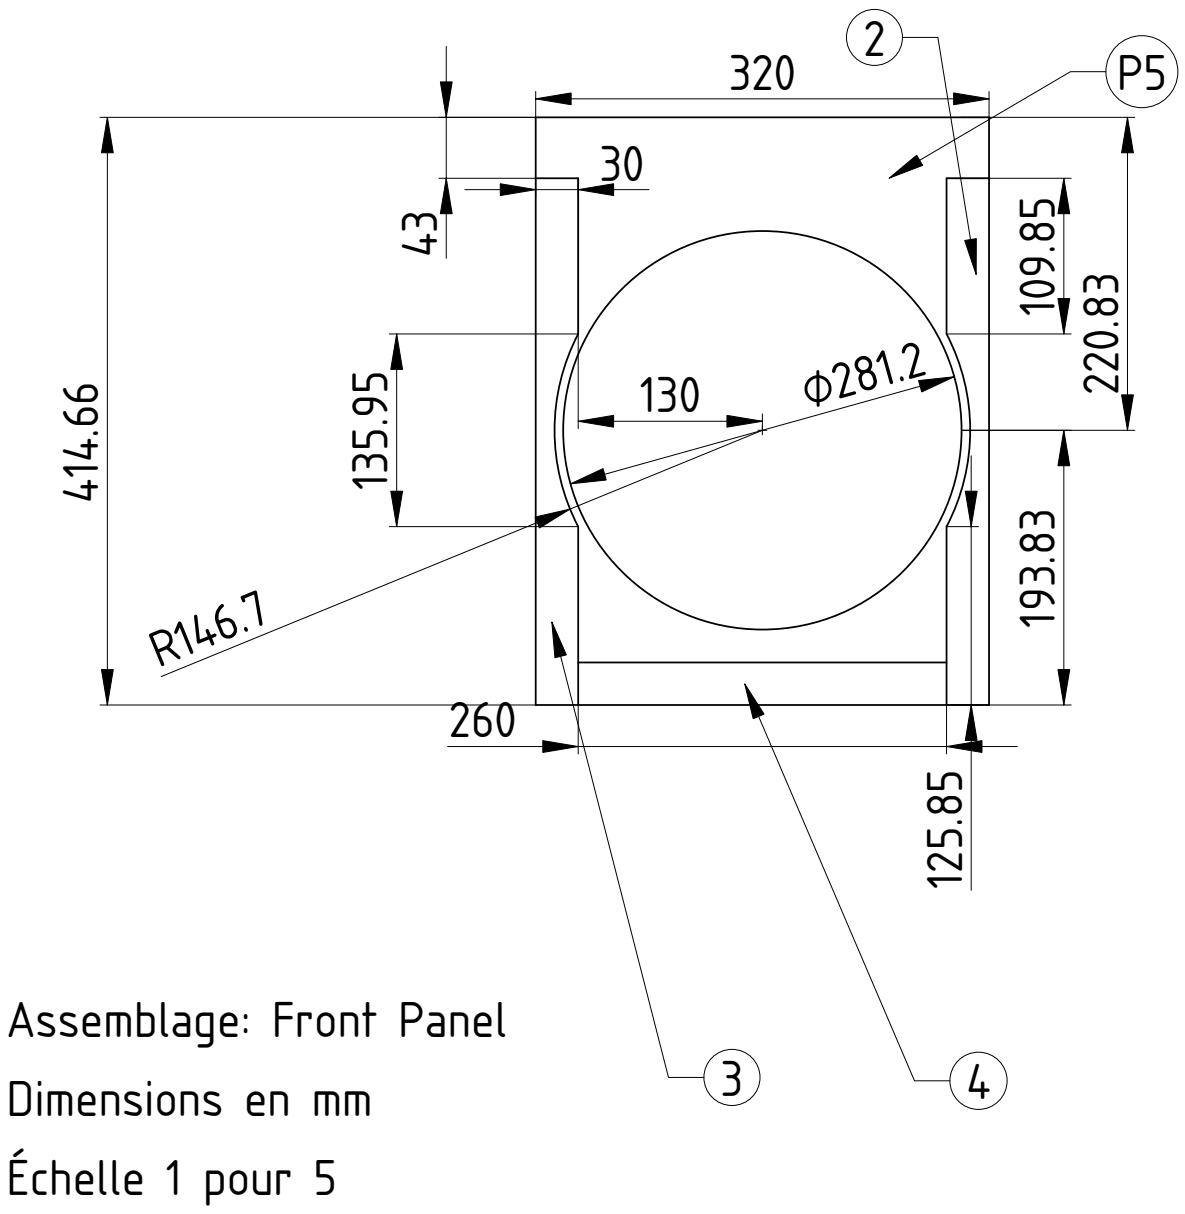
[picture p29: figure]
Assemblage: Front Panel Dimensions en mm Échelle 1 pour 5
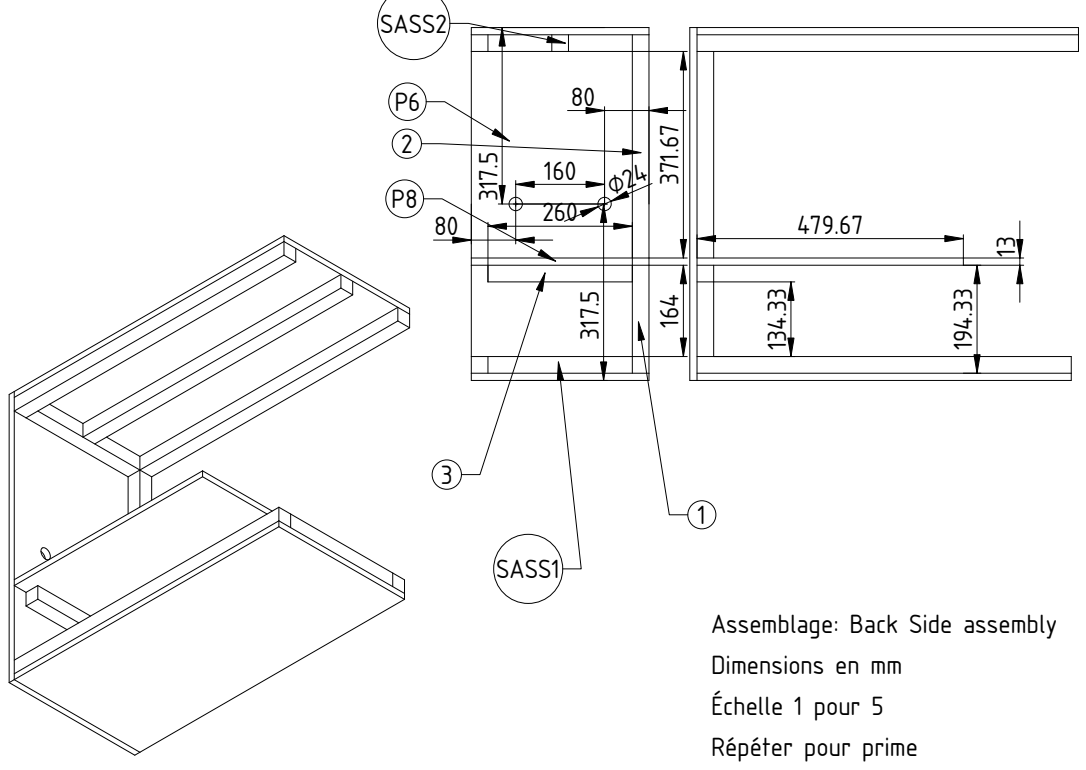
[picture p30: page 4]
SASS2; SASS1

Assemblage: Back Side assembly
Dimensions en mm
Échelle 1 pour 5

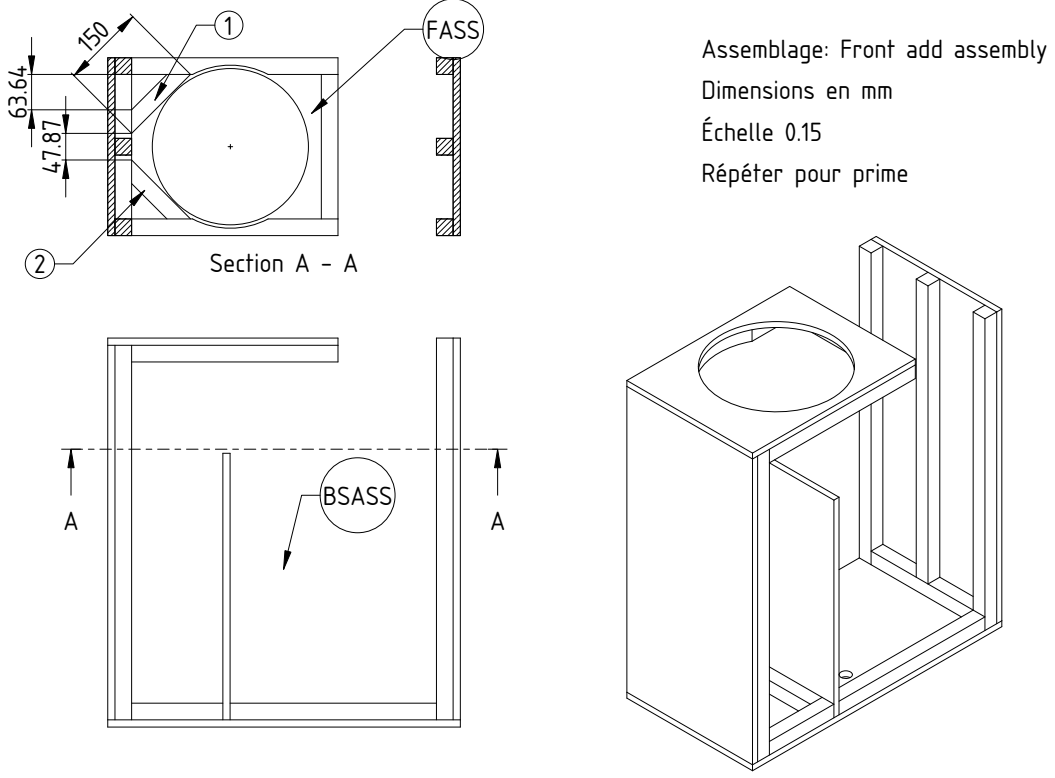
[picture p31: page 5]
Section A - A; FASS; BSASS

Assemblage: Front add assembly
Dimensions en mm
Échelle 0.15
Répéter pour prime

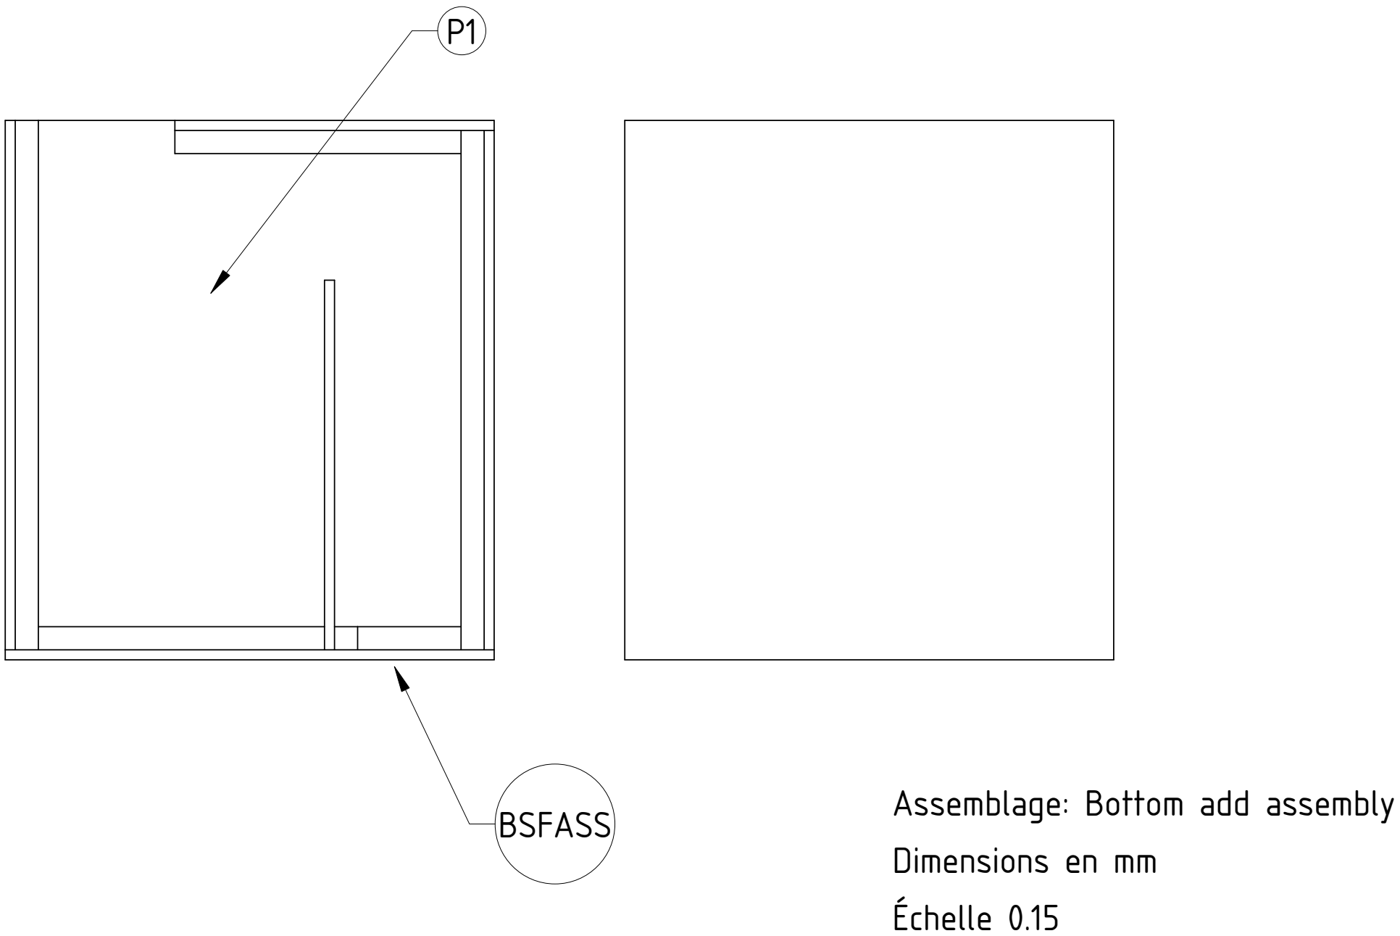
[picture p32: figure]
BSFASS; Assemblage: Bottom add assembly; Dimensions en mm Échelle 0.15

Assemblage: Bottom Fin support
Dimensions en mm
Échelle 0.15
Répéter pour prime


Assemblage: middle brace
Dimensions en mm
Échelle 0.15

Assemblage: middle fin support; Dimensions en mm Échelle 0.15

Assemblage: top brace
Dimensions en mm
Échelle 0.15


Assemblage: close it up!
Dimensions en mm
Échelle 0.15

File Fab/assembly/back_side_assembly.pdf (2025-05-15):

SASS2; SASS1

Assemblage: Back Side assembly
Dimensions en mm
Échelle 1 pour 5
Répéter pour prime

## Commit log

2025-02-27 Premiere simulations
    [boxplan.xls]
2025-02-27 Made changes to horn resp simulations to get proper driver placement
    [boxplan.ods, boxplan.xls]
2025-02-28 Ajout du CAD de la boite
    [boite_lightcon_C231999.FCStd]
2025-03-11 Improved design for flat acoustic power spectrum and group delay
    [boxplan.ods]
2025-03-14 Modified PA310 sims to account for max X and added 12LF design and sim
    [boxplan.ods, boxplan_apollo12lf.ods, boxplan_pa310.ods]
2025-03-29 G-FOLD V1 avec filtre actif. Pas verifie si ca marche geometriquement
    [gfold.FCStd]
2025-03-30 Added FreeCad boxplan implementation of G-Fold with Hornresp paramters calculation
    [gfold.FCStd]
2025-03-30 Design pour Apollo 12LF
    [boxplan_apollo12lf.ods, boxplan_pa310.ods, gfold.FCStd]
2025-03-30 Added filter to Apollo12lF Gfold
2025-03-30 Design with PA310
    [gfold.FCStd]
2025-04-08 With Delta-12LFC
    [gfold.FCStd]
2025-04-11 Version with 8ohms (LFA)
    [gfold.FCStd]
2025-04-12 Added detailed cut plan and CAD of box. Missing bracing
    [gfold.FCStd]
2025-04-13 Bracing fait! bon pour la fab
    [gfold.FCStd]
2025-04-15 Bracing modif done. Plan de coupe aussi
    [gfold.FCStd, master_fab.ods]
2025-04-21 Bracing en panneaux et gestion dinventaire
    [gfold.FCStd, master_fab.ods]
2025-04-21 updated cut plan
2025-04-26 Managed to make the panels fit without changing the design
    [gfold.FCStd]
2025-04-26 Final Fab and cut plans
    [gfold.FCStd, master_fab.ods]
2025-05-09 assembly plan of side panel 1 done
    [gfold.FCStd, master_fab.ods]
2025-05-11 Added assembly back, front, back side
    [gfold.FCStd, master_fab.ods]
2025-05-12 bottom add, fin support assembly steps added
    [gfold.FCStd, master_fab.ods]
2025-05-13 Added holes for connector, connector schem and finished build plan
    [gfold.FCStd, master_fab.ods]
2025-05-15 Final version of assembly
    [gfold.FCStd, master_fab.ods]
2025-06-01 Cleanup of Readme
    [gfold.FCStd]
